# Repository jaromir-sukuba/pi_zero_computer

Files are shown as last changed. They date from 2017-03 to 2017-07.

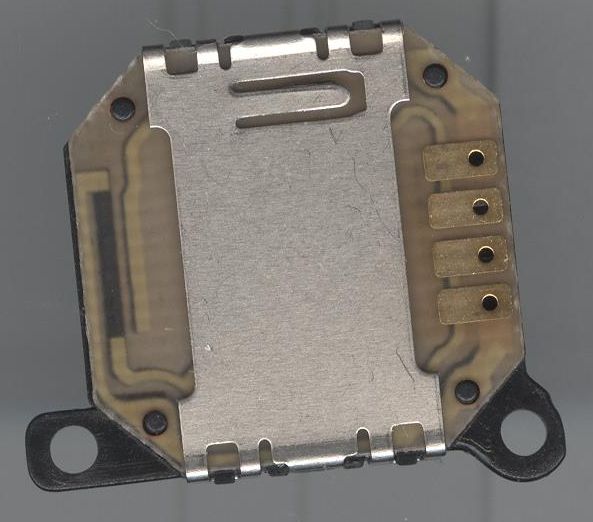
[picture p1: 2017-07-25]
other/joystick_600dpi.jpg

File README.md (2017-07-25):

# Raspberry pi portable computer #

## What it is ##
This is small handheld computer, built around Raspberry Pi Zero, referred as RPi in following articles. Though RPi is often thought to be complete computer, it isn't. You need to add some kind of display, input devices (mouse, keyboard or similar), power supply and perhaps network connection to make it usable by today standards.

My decision was to pack it into small portable form. Raspberry pi laptops have been done to death online, but all of them do miss some features I like to have:

1. All-in-one form factor. I don't want one box for brains, another box for BT keyboard, another for USB hub etc... It is simpler from construction point of view, but the device isn't much usable nor portable.
2. Enclosure sturdy enough so I can put the computer into by backpack with no worries of its disintegration. 
3. At least two USB ports, audio output, battery life at least 5 hours.
4. No major modifications to Raspberry pi. 
5. Easy to replicate by others. I mean - off the shelf components, no complicated wiring (once the PCB is done).

I must admit this computer goes in line with my long term "portable computer fixation", exhibited [before](https://hackaday.io/project/18445-brainfcktor), [and here](https://hackaday.io/project/3511-pavapro-portable-avr-programmer), [also here](https://hackaday.io/project/1757-pp04-camel-computer) or [here too](https://hackaday.io/project/643-minibsd-laptop-computer).



## What it isn't ##
This device isn't superior to thousands or millions manhours of cummulative work put even into the cheapest smartphone you can buy at usual sources. Despite all the work invested into the devices, those are fit to majority of users and (from obvious reasons) often miss details vital for folks like me - full sized USB ports or GPIO pins attached to main processor or 3,5mm audio jack.

## FAQ ##
Q: How is this better than my phone/tablet/smart toaster?

A: If you need to ask this question, then it isn't any better.

## Hardware ##
All hardware is monted on two PCBs, sandwitched together.

The smaller one contains TFT display and a few minor components, vast majority of components is on bottom PCB.



The circuit seems to be complex, but in fact it's only a bit convoluted power supply and user interface. 

RPi acts as heart of this, with USB hub based on FE1.1s, attached to WiFi module, STM32F072 enumerating as USB HID device with two interfaces - one for keyboard (operated by 4x4 matrix keyboard) and one for mouse (operated by analog joystick and three discrete buttons). Audio comes as no surprise to Raspberry pi users, it done by low-pass RC filter and jelly-bean TDA1308 in most common circuit. STM32L011 is connected to RPi by means of serial interface and can turn on/off three power supply voltages (for RPi, for USB, for WiFi) on request of RPi or user. Power is taken from two LiPo cells in series, those are charged by MCP73844 from external 10V source.

Enclosure is designed in FreeCad and printed on hobbyist grade DIY 3D printer

Though self tapered screws would do the job too, I used threaded inserts for machined screws, to allow multiple open-close cycles.


Software
I tried to use as little custom software as possible and rely on existing software drivers. That is behind decision of placing the keyboard behind USB HID wall or using RTL8188EUS module for WiFi. Despite that, device doesn't work as-is with mainstream Raspbian distribution, some customized setup is needed.

* download raspbian, create bootable uSD card and put file ssh.txt into /boot of the uSD card - to allow ssh access to RPi
* connect USB-Ethernet convertor into one USB port of device. 3USD one from Asian sources will do the job
* start device, wait a bit, discover it's IP, login, run raspi-config, setup new password, expand filesystem
* run sudo apt-get update
* run sudo apt-get upgrade
* Add to file /etc/modules-load.d/fbtft.conf
> 	spi-bcm2835
> 	fbtft_device

* Add to file /etc/modprobe.d/fbtft.conf
> 	options fbtft_device custom name=fb_ili9341 gpios=reset:25,dc:24,led:18 speed=16000000 rotate=90 bgr=1

* sudo nano /boot/config.txt
> 	dtoverlay=rpi-display

* sudo reboot
*	sudo nano /boot/cmdline.txt
	
> 	fbcon=map:10 fbcon=font:VGA7x14 logo.nologo

*	sudo nano /usr/share/X11/xorg.conf.d/99-fbdev.conf
> 		Section "Device"
> 		  Identifier "bla"
> 		  Driver "fbdev"
> 		  Option "fbdev" "/dev/fb1"
> 		EndSection
 		
 now you should be able to see display working

* in /boot/config.txt add the following line to enable audio interface:
>     dtoverlay=pwm-2chan,pin=18,func=2,pin2=13,func2=4
>     audio_pwm_mode=2
	
* sudo reboot
* sudo apt-get purge rfkill - to prevent WiFi module from sleeping

## Arduino, just for blog cred ##
Yes, you can upload your arduino sketches in the field


## Miscellany ##
More info is to be found on my [hackady.io page](https://hackaday.io/project/19437-raspberry-pi-zero-handheld-computer)

This project is licensed by MIT license, see LICENSE.md file

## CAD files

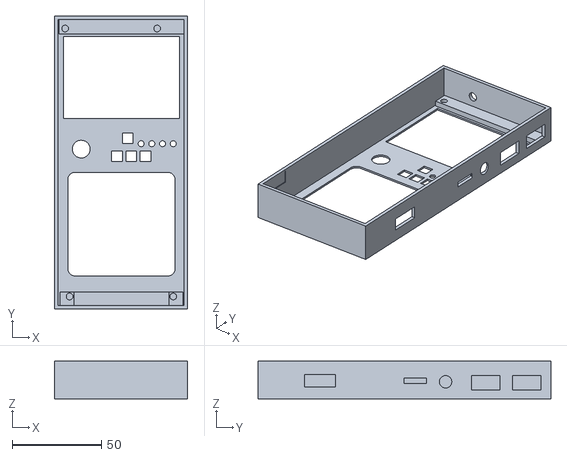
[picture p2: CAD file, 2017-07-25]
mech/1c_main.stl
74.5 x 164.0 x 21.0

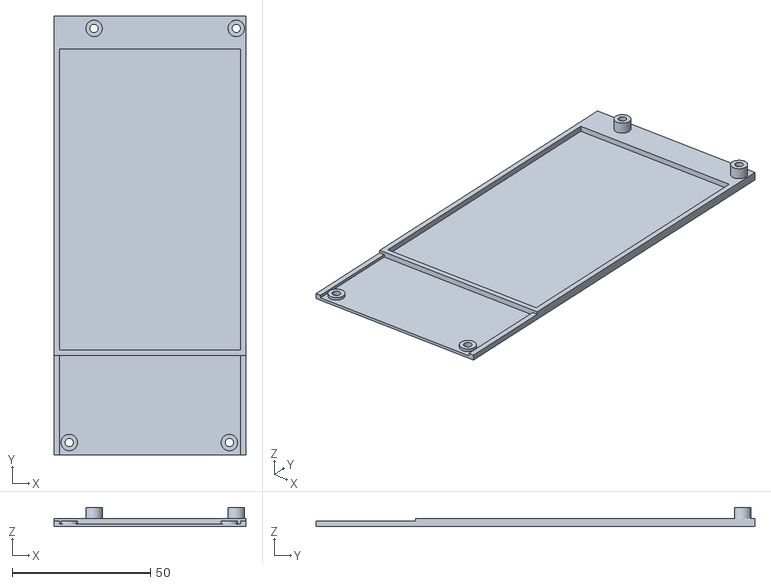
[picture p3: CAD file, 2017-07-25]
mech/1c_btm.stl
69.5 x 159.0 x 7.00

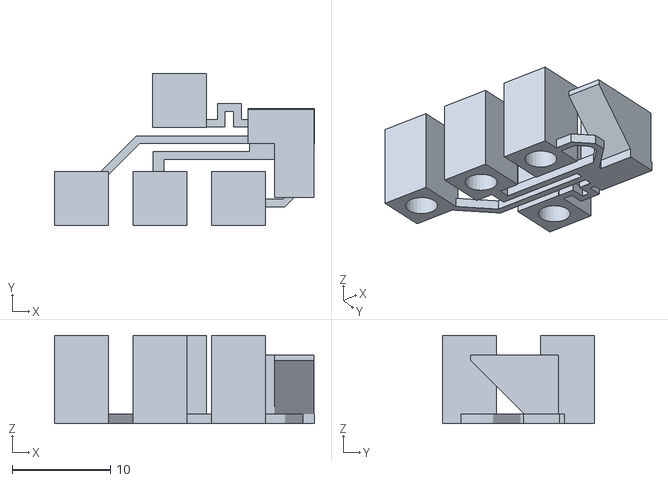
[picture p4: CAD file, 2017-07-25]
mech/1c_btn.stl
26.5 x 15.5 x 9.00

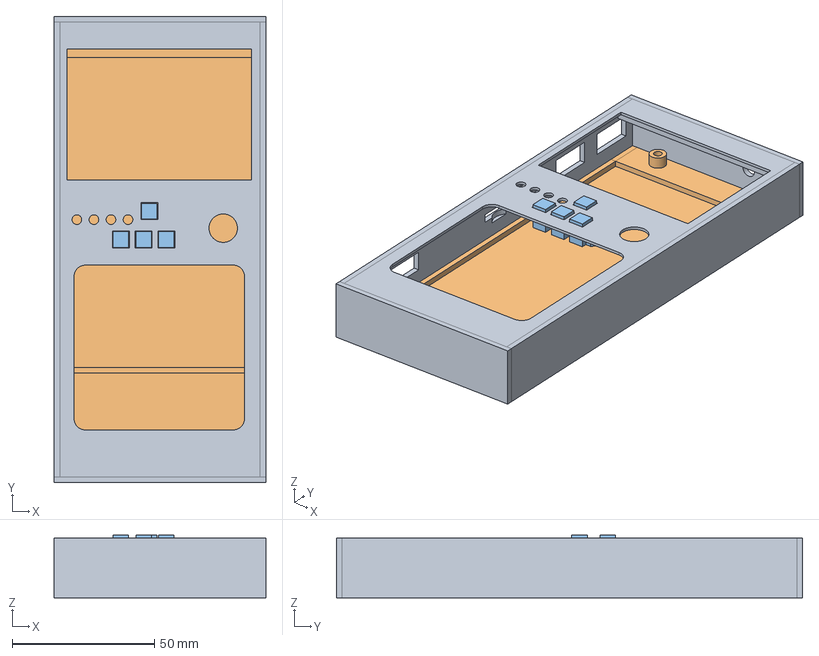
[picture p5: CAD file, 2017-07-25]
mech/m1c.FCStd
74.5 x 164.0 x 22.0 mm
h_plate
buttons

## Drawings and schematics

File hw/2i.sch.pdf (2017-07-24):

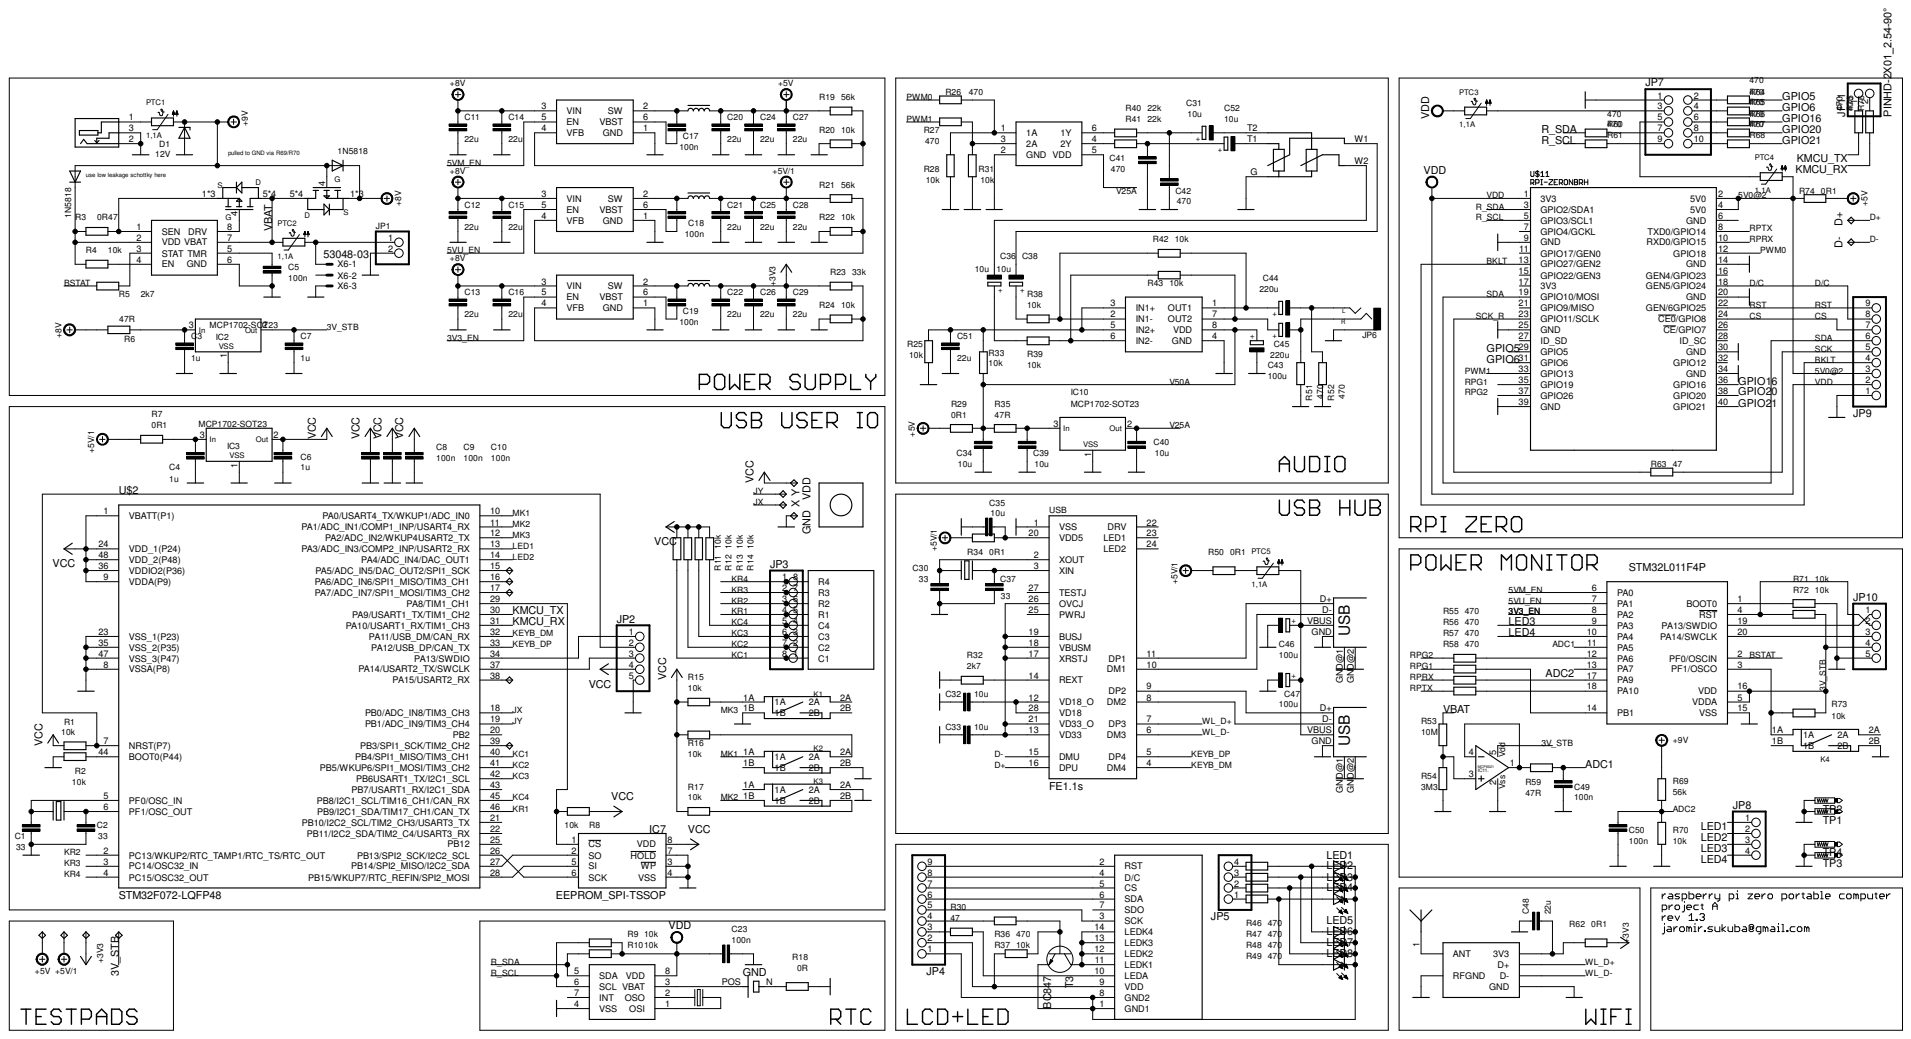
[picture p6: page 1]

+ pulled to GND via R69/R70

use low leakage schottky here

VD18 28 | 7
VD33 13 | 6 DP3 | VBUS

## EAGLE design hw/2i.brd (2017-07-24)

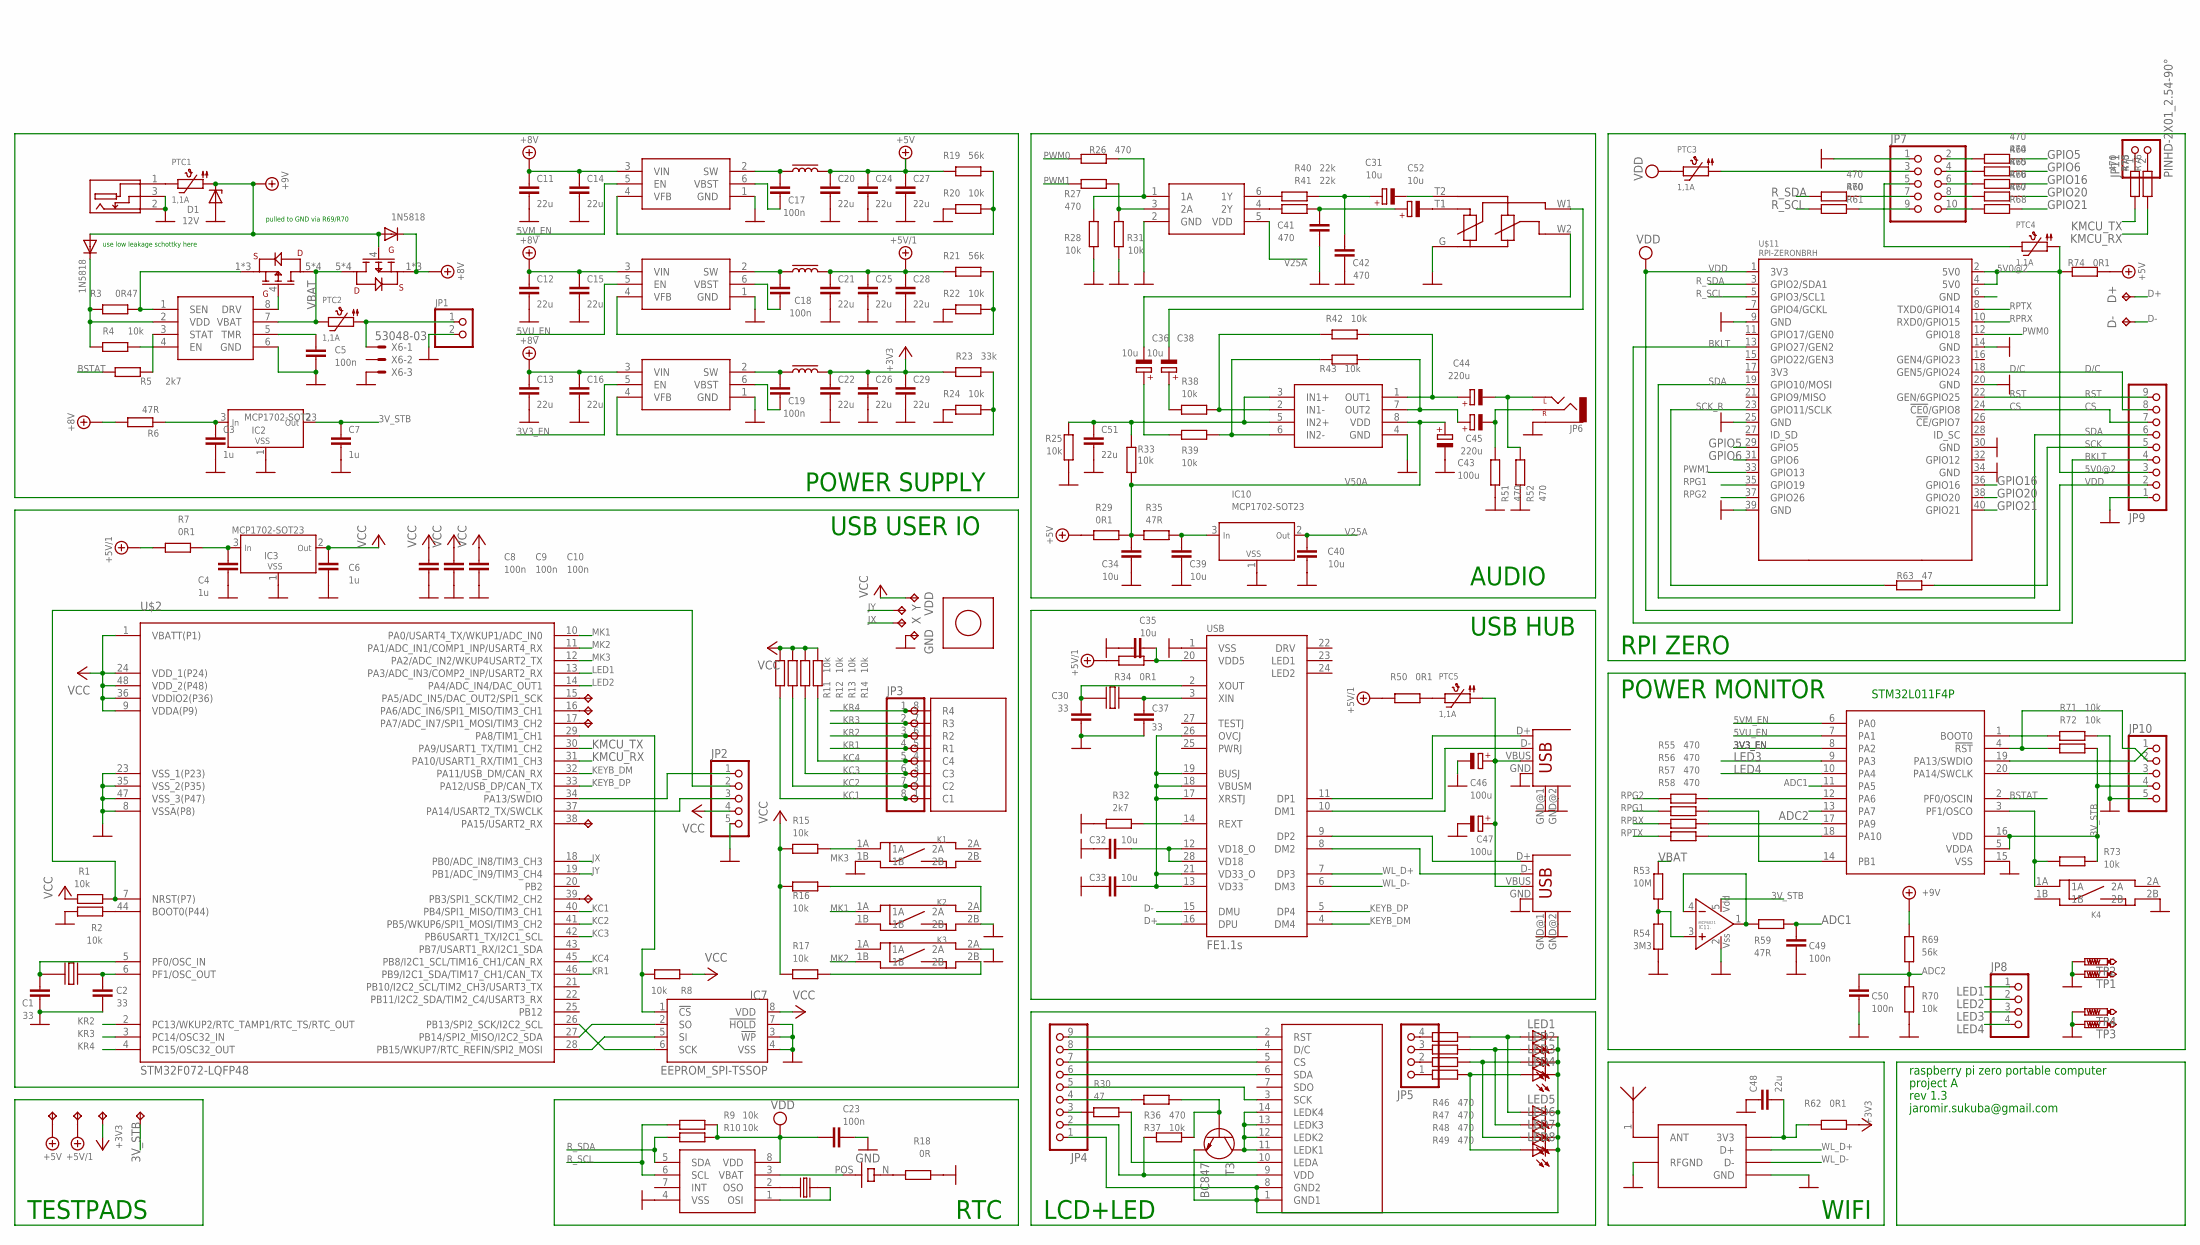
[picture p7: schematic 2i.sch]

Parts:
ANT1: ANT_RAINSUN_24GHZ; ANT_RAINSUN-24G
C1, C2, C30, C37: 33; R0805
C3, C4, C6, C7: 1u; R0805
C5, C8, C9, C10, C17, C18, C19, C23, C49, C50: 100n; R0805
C11, C12, C13, C14, C15, C16, C20, C21, C22, C24, C25, C26, C27, C28, C29, C48, C51: 22u; R0805
C31, C36, C38, C52: 10u; PANASONIC_A
C32, C33, C34, C35, C39, C40: 10u; R0805
C41, C42: 470; R0805
C43, C46, C47: 100u; PANASONIC_D
C44, C45: 220u; PANASONIC_D
D1: 12V; SMB
D2, D3: 1N5818; SMB
D+: TPTP14R; TP14R
D-: TPTP14R; TP14R
GND: TPTP14R; TP14R
IC1: MCP73844; MSOP8
IC2, IC3, IC10: MCP1702-SOT23; SOT23
IC4, IC5, IC6: TPS562200; SOT23-6
IC7: EEPROM_SPI-TSSOP; TSSOP8W
IC8: PCF8523; SO-08
IC9: 74LVC2G34; SOT23-6
IC11: MCP6021; SOT23-5L
JP1: PINHD-1X02_2.54-90°; 1X02/90
JP2, JP10: PINHD-1X05_2.54-90°; 1X05/90
JP3: PINHD-1X08_2.54; 1X08
JP4, JP9: PINHD-1X09_2.00; 1X09M
JP5, JP8: PINHD-1X04_2.00; 1X04M
JP6: AUDIO-JACKPTH; AUDIO-JACK
JP7: PINHD-2X05_2.54-90°; 2X05/90
JP11: PINHD-2X01_2.54-90°; 2X01/90
K1, K2, K3, K4: SWITCH_BD_B; SW_SMD2
LED1, LED2, LED3, LED4: LED3MM
LED5, LED6, LED7, LED8: LEDCHIPLED_0805; CHIPLED_0805
MOD1: MOD_USB_RTL8188
PTC1, PTC2, PTC3, PTC4, PTC5: 1,1A; PTC1812
Q1: CRYSTAL87X38; CRYST_32K_87X38MM
R1, R2, R4, R8, R9, R10, R11, R12, R13, R14, R15, R16, R17, R20, R22, R24, R25, R28, R31, R33, R37, R38, R39, R42, R43, R70, R71, R72, R73: 10k; R0805
R3: 0R47; R1206
R5, R32: 2k7; R0805
R6, R35, R59: 47R; R0805
R7, R29, R34, R50, R62, R74: 0R1; R1206
R18: 0R; R0805
R19, R21, R69: 56k; R0805
R23: 33k; R0805
R26, R27, R36, R46, R47, R48, R49, R51, R52, R55, R56, R57, R58, R60, R61, R64, R65, R66, R67, R68, R75, R76: 470; R0805
R30, R63: 47; R0805
R40, R41: 22k; R0805
R53: 10M; R0805
R54: 3M3; R0805
T1, T2: PFET_SO8; SO-08
T3: BC847; SOT23
TFT1: DISP_ILI_28
TP1, TP2, TP3, TP4: PTR1PAD1-13; P1-13
U$1: CONN_DC_13; CON_DC13
U$2: STM32F072-LQFP48; LQFP48
U$3, U$4, U$5: 2u2; BOURNS_SRP7030
U$6: BATTH1220; BATT_HOLDER_DS1092-12
U$7: KB1604
U$8: JOY_PS
U$9: TDA1308; SO-08
U$10: POT_DUAL_14X2; POT_14X2DUAL
U$11: RPI-ZERONBRH; RPI_ZERO_NBRH
U$12: STM32F030_20; TSSOP20
USB: FE1.1S; FE1.1S_SSOP-28
USB1, USB2: USB-A-S
VDD: TPTP14R; TP14R
X, X1, X3, X4, X5, X7, X8, X9, X12, X13: TPTP14R; TP14R
X2, X14: CRYST_TC26SMXAS; CR_12SMXA_S
X6: 53048-03
Y: TPTP14R; TP14R

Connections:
3V3_EN: IC6.5 (EN), U$12.8 (PA2)
3V_STB: C7.1, IC2.2 (OUT), IC11.5 (VDD), JP10.4, R72.2, R73.2, U$12.5 (VDDA), U$12.16 (VDD), X5.TP
5V0@2: JP9.3, PTC4.P$1 (1), R74.2, U$11.2 (5V0), U$11.4 (5V0)
5VM_EN: IC4.5 (EN), U$12.6 (PA0)
5VU_EN: IC5.5 (EN), U$12.7 (PA1)
+3V3: C22.1, C26.1, C29.1, R23.1, R62.1, U$5.P$2, X4.TP
+5V: C20.1, C24.1, C27.1, R19.1, R29.2, R74.1, U$3.P$2, X1.TP
+5V/1: C21.1, C25.1, C28.1, R7.1, R21.1, R34.2, R50.2, U$4.P$2, X3.TP
+8V: C11.1, C12.1, C13.1, C14.1, C15.1, C16.1, D3.C, IC4.3 (VIN), IC5.3 (VIN), IC6.3 (VIN), R6.2, T2.1 (S), T2.2 (S), T2.3 (S)
+9V: D1.C, D2.A, D3.A, PTC1.P$1 (1), R69.2, T2.4 (G)
ADC1: C49.2, R59.1, U$12.11 (PA5)
ADC2: C50.2, R69.1, R70.2, U$12.13 (PA7)
BKLT: JP9.4, U$11.13 (GPIO27/GEN2)
BSTAT: R5.2, U$12.2 (PF0/OSCIN)
CS: JP9.7, U$11.24 (!CE0!/GPIO8)
D+: D+.TP, USB.16 (DPU)
D-: D-.TP, USB.15 (DMU)
D/C: JP9.8, U$11.18 (GEN5/GPIO24)
GND: C1.1, C2.1, C3.2, C4.2, C5.2, C6.2, C7.2, C8.2, C9.2, C10.2, C11.2, C12.2, C13.2, C14.2, C15.2, C16.2, C20.2, C21.2, C22.2, C23.2, C24.2, C25.2, C26.2, C27.2, C28.2, C29.2, C30.1, C32.1, C33.1, C34.1, C35.1, C37.1, C39.1, C40.1, C41.1, C42.1, C43.-, C46.-, C47.-, C48.1, C49.1, C50.1, C51.2, D1.A, GND.TP, IC1.6 (GND), IC2.1 (VSS), IC3.1 (VSS), IC4.1 (GND), IC5.1 (GND), IC6.1 (GND), IC7.3 (!WP), IC7.4 (VSS), IC7.7 (!HOLD), IC8.4 (VSS), IC9.2 (GND), IC10.1 (VSS), IC11.2 (VSS), JP1.2, JP2.5, JP6.SLEEVE, JP7.1, JP9.1, JP10.5, K1.1B, K2.2B, K3.2A, K4.2B, MOD1.GND, MOD1.RFGND, R2.2, R18.1, R20.1, R22.1, R24.1, R25.1, R28.1, R31.1, R32.1, R51.2, R52.2, R54.1, R70.1, R71.2, TP1.TP, TP2.TP, TP3.TP, TP4.TP, U$1.2 (N), U$1.3 (SW), U$2.8 (VSSA(P8)), U$2.23 (VSS_1(P23)), U$2.35 (VSS_2(P35)), U$2.47 (VSS_3(P47)), U$9.4 (GND), U$10.G, U$11.9 (GND), U$11.14 (GND), U$11.20 (GND), U$11.25 (GND), U$11.30 (GND), U$11.34 (GND), U$11.39 (GND), U$12.15 (VSS), USB.1 (VSS), USB1.GND, USB1.GND@1 (GND), USB1.GND@2 (GND), USB2.GND, USB2.GND@1 (GND), USB2.GND@2 (GND), X6.3
GND@8: U$11.6 (GND)
GPIO5: R64.2, U$11.29 (GPIO5)
GPIO6: R65.2, U$11.31 (GPIO6)
GPIO16: R66.2, U$11.36 (GPIO16)
GPIO20: R67.2, U$11.38 (GPIO20)
GPIO21: R68.2, U$11.40 (GPIO21)
JX: U$2.18 (PB0/ADC_IN8/TIM3_CH3), X.TP
JY: U$2.19 (PB1/ADC_IN9/TIM3_CH4), Y.TP
KC1: JP3.8, R11.1, U$2.40 (PB4/SPI1_MISO/TIM3_CH1), U$7.1 (C1)
KC2: JP3.7, R12.1, U$2.41 (PB5/WKUP6/SPI1_MOSI/TIM3_CH2), U$7.2 (C2)
KC3: JP3.6, R13.1, U$2.42 (PB6USART1_TX/I2C1_SCL), U$7.3 (C3)
KC4: JP3.5, R14.1, U$2.45 (PB8/I2C1_SCL/TIM16_CH1/CAN_RX), U$7.4 (C4)
KEYB_DM: U$2.32 (PA11/USB_DM/CAN_RX), USB.4 (DM4)
KEYB_DP: U$2.33 (PA12/USB_DP/CAN_TX), USB.5 (DP4)
KMCU_RX: R76.1, U$2.31 (PA10/USART1_RX/TIM1_CH3)
KMCU_TX: R75.1, U$2.30 (PA9/USART1_TX/TIM1_CH2)
KR1: JP3.4, U$2.46 (PB9/I2C1_SDA/TIM17_CH1/CAN_TX), U$7.5 (R1)
KR2: JP3.3, U$2.2 (PC13/WKUP2/RTC_TAMP1/RTC_TS/RTC_OUT), U$7.6 (R2)
KR3: JP3.2, U$2.3 (PC14/OSC32_IN), U$7.7 (R3)
KR4: JP3.1, U$2.4 (PC15/OSC32_OUT), U$7.8 (R4)
LED1: JP8.1, U$2.13 (PA3/ADC_IN3/COMP2_INP/USART2_RX)
LED2: JP8.2, U$2.14 (PA4/ADC_IN4/DAC_OUT1)
LED3: JP8.3, U$12.9 (PA3)
LED4: JP8.4, U$12.10 (PA4)
MK1: K2.1A, U$2.10 (PA0/USART4_TX/WKUP1/ADC_IN0)
MK2: K3.1B, U$2.11 (PA1/ADC_IN1/COMP1_INP/USART4_RX)
MK3: K1.1A, R15.2, U$2.12 (PA2/ADC_IN2/WKUP4USART2_TX)
unnamed: C35.2, R34.1, USB.20 (VDD5)
unnamed: C17.2, IC4.2 (SW), U$3.P$1
unnamed: JP4.3, R30.2
unnamed: IC7.6 (SCK), U$2.26 (PB13/SPI2_SCK/I2C2_SCL)
unnamed: R36.2, R37.1, T3.1 (B)
unnamed: JP4.4, R36.1
unnamed: IC1.1 (SEN), R3.2, T1.1 (S), T1.2 (S), T1.3 (S)
unnamed: USB.9 (DP2), USB2.D+
unnamed: USB.8 (DM2), USB2.D-
unnamed: USB.10 (DM1), USB1.D-
unnamed: IC1.8 (DRV), T1.4 (G)
unnamed: IC1.4 (EN), R4.2
unnamed: USB.11 (DP1), USB1.D+
unnamed: C33.2, USB.13 (VD33), USB.17 (XRSTJ), USB.18 (VBUSM), USB.19 (BUSJ), USB.21 (VD33_O), USB.26 (OVCJ)
unnamed: IC11.1 (VYSTUP), IC11.4 (IN-), R59.2
unnamed: C32.2, USB.12 (VD18_O), USB.28 (VD18)
unnamed: C5.1, IC1.5 (TMR)
unnamed: C17.1, IC4.6 (VBST)
unnamed: R32.2, USB.14 (REXT)
unnamed: IC4.4 (VFB), R19.2, R20.2
unnamed: C30.2, USB.2 (XOUT), X14.P$1
unnamed: C18.2, IC5.2 (SW), U$4.P$1
unnamed: C18.1, IC5.6 (VBST)
unnamed: C37.2, USB.3 (XIN), X14.P$2
unnamed: C46.+, C47.+, PTC5.P$1 (1), USB1.VBUS, USB2.VBUS
unnamed: IC7.2 (SO), U$2.27 (PB14/SPI2_MISO/I2C2_SDA)
unnamed: IC9.6 (1Y), R40.2
unnamed: IC9.4 (2Y), R41.2
unnamed: C31.+, C42.2, R40.1
unnamed: C41.2, C52.+, R41.1
unnamed: C44.-, JP6.TIP (LEFT), R52.1
unnamed: C45.-, JP6.RING (RIGHT), R51.1
unnamed: C44.+, R42.2, U$9.1 (OUT1)
unnamed: C45.+, R43.2, U$9.7 (OUT2)
unnamed: C51.1, R25.2, R33.1, U$9.3 (IN1+), U$9.5 (IN2+)
unnamed: R38.2, R42.1, U$9.2 (IN1-)
unnamed: R39.2, R43.1, U$9.6 (IN2-)
unnamed: C38.+, R38.1
unnamed: C36.+, R39.1
unnamed: C36.-, U$10.W2
unnamed: C38.-, U$10.W1
unnamed: ANT1.1, MOD1.ANT
unnamed: JP11.1, R75.2
unnamed: IC5.4 (VFB), R21.2, R22.2
unnamed: C19.2, IC6.2 (SW), U$5.P$1
unnamed: C19.1, IC6.6 (VBST)
unnamed: JP2.1, U$2.34 (PA13/SWDIO)
unnamed: IC6.4 (VFB), R23.2, R24.2
unnamed: C4.1, IC3.3 (IN), R7.2
unnamed: JP2.3, U$2.37 (PA14/USART2_TX/SWCLK)
unnamed: D2.C, IC1.2 (VDD), R3.1, R4.1
unnamed: PTC1.P$2 (2), U$1.1
unnamed: IC9.1 (1A), R26.1, R28.2
unnamed: IC9.3 (2A), R27.1, R31.2
unnamed: C1.2, U$2.5 (PF0/OSC_IN), X2.P$1
unnamed: JP11.2, R76.2
unnamed: IC7.5 (SI), U$2.28 (PB15/WKUP7/RTC_REFIN/SPI2_MOSI)
unnamed: IC7.1 (!CS), R8.2, U$2.29 (PA8/TIM1_CH1)
unnamed: R56.2, U$12.14 (PB1)
unnamed: U$2.15 (PA5/ADC_IN5/DAC_OUT2/SPI1_SCK), X7.TP
unnamed: R2.1, U$2.44 (BOOT0(P44))
unnamed: JP5.4, R46.2
unnamed: JP5.3, R47.2
unnamed: JP5.2, R48.2
unnamed: JP5.1, R49.2
unnamed: JP2.2, R1.1, U$2.7 (NRST(P7))
unnamed: R57.2, U$12.17 (PA9)
unnamed: R58.2, U$12.18 (PA10)
unnamed: PTC5.P$2 (2), R50.1
unnamed: R55.2, U$12.12 (PA6)
unnamed: U$2.16 (PA6/ADC_IN6/SPI1_MISO/TIM3_CH1), X8.TP
unnamed: U$2.17 (PA7/ADC_IN7/SPI1_MOSI/TIM3_CH2), X9.TP
unnamed: U$2.38 (PA15/USART2_RX), X12.TP
unnamed: U$2.39 (PB3/SPI1_SCK/TIM2_CH2), X13.TP
unnamed: JP10.1, U$12.19 (PA13/SWDIO)
unnamed: JP10.3, U$12.20 (PA14/SWCLK)
unnamed: JP10.2, R72.1, U$12.4 (!RST)
unnamed: JP1.1, PTC2.P$1 (1), X6.1
unnamed: C52.-, U$10.T1
unnamed: K4.1A, R73.1, U$12.3 (PF1/OSCO)
unnamed: C2.2, U$2.6 (PF1/OSC_OUT), X2.P$2
unnamed: IC8.3 (VBAT), U$6.POS
unnamed: R18.2, U$6.N (M)
unnamed: LED1.A, LED5.A, R46.1
unnamed: LED2.A, LED6.A, R47.1
unnamed: K3.2B, R17.2
unnamed: IC8.2 (OSO), Q1.4 (2)
unnamed: IC8.1 (OSI), Q1.1
unnamed: K2.2A, R16.2
unnamed: LED3.A, LED7.A, R48.1
unnamed: LED4.A, LED8.A, R49.1
unnamed: JP4.5, TFT1.3 (SCK)
unnamed: JP4.1, LED1.K (C), LED2.K (C), LED3.K (C), LED4.K (C), LED5.C, LED6.C, LED7.C, LED8.C, T3.2 (E), TFT1.1 (GND1), TFT1.8 (GND2)
unnamed: T3.3 (C), TFT1.11 (LEDK1), TFT1.12 (LEDK2), TFT1.13 (LEDK3), TFT1.14 (LEDK4)
unnamed: JP7.5, PTC4.P$2 (2)
unnamed: IC1.3 (STAT), R5.1
unnamed: JP7.3, PTC3.P$1 (1)
unnamed: C48.2, MOD1.3V3, R62.2
unnamed: IC11.3 (NEIN+), R53.1, R54.2
unnamed: C3.1, IC2.3 (IN), R6.1
unnamed: R71.1, U$12.1 (BOOT0)
unnamed: C31.-, U$10.T2
unnamed: R30.1, TFT1.10 (LEDA)
unnamed: JP4.2, R37.2, TFT1.9 (VDD)
unnamed: C39.2, IC10.3 (IN), R35.2
unnamed: JP4.6, TFT1.6 (SDA)
unnamed: JP4.7, TFT1.5 (CS)
unnamed: JP4.8, TFT1.4 (D/C)
unnamed: JP4.9, TFT1.2 (RST)
unnamed: JP7.10, R68.1
unnamed: JP7.8, R67.1
unnamed: JP7.6, R66.1
unnamed: JP7.4, R65.1
unnamed: JP7.2, R64.1
unnamed: JP7.7, R60.2
unnamed: JP7.9, R61.2
PWM0: R27.2, U$11.12 (GPIO18)
PWM1: R26.2, U$11.33 (GPIO13)
RPG1: R56.1, U$11.35 (GPIO19)
RPG2: R55.1, U$11.37 (GPIO26)
RPRX: R57.1, U$11.10 (RXD0/GPIO15)
RPTX: R58.1, U$11.8 (TXD0/GPIO14)
RST: JP9.9, U$11.22 (GEN/6GPIO25)
R_SCL: IC8.6 (SCL), R9.1, R61.1, U$11.5 (GPIO3/SCL1)
R_SDA: IC8.5 (SDA), R10.1, R60.1, U$11.3 (GPIO2/SDA1)
SCK: JP9.5, R63.1
SCK_R: R63.2, U$11.23 (GPIO11/SCLK)
SDA: JP9.6, U$11.19 (GPIO10/MOSI)
V25A: C40.2, IC9.5 (VDD), IC10.2 (OUT)
V50A: C34.2, C43.+, R29.1, R33.2, R35.1, U$9.8 (VDD)
VBAT: IC1.7 (VBAT), PTC2.P$2 (2), R53.2, T1.5 (D), T1.6 (D), T1.7 (D), T1.8 (D), T2.5 (D), T2.6 (D), T2.7 (D), T2.8 (D)
VCC: C6.1, C8.1, C9.1, C10.1, IC3.2 (OUT), IC7.8 (VDD), JP2.4, R1.2, R8.1, R11.2, R12.2, R13.2, R14.2, R15.1, R16.1, R17.1, U$2.1 (VBATT(P1)), U$2.9 (VDDA(P9)), U$2.24 (VDD_1(P24)), U$2.36 (VDDIO2(P36)), U$2.48 (VDD_2(P48)), VDD.TP
VDD: C23.1, IC8.8 (VDD), JP9.2, PTC3.P$2 (2), R9.2, R10.2, U$11.1 (3V3)
WL_D+: MOD1.D+, USB.7 (DP3)
WL_D-: MOD1.D-, USB.6 (DM3)

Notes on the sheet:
POWER SUPPLY
USB USER IO
RPI ZERO
POWER MONITOR
WIFI
LCD+LED
USB HUB
AUDIO
raspberry pi zero portable computer
project A
rev 1.3
RTC
jaromir.sukuba@gmail.com
pulled to GND via R69/R70
use low leakage schottky here
TESTPADS
STM32L011F4P

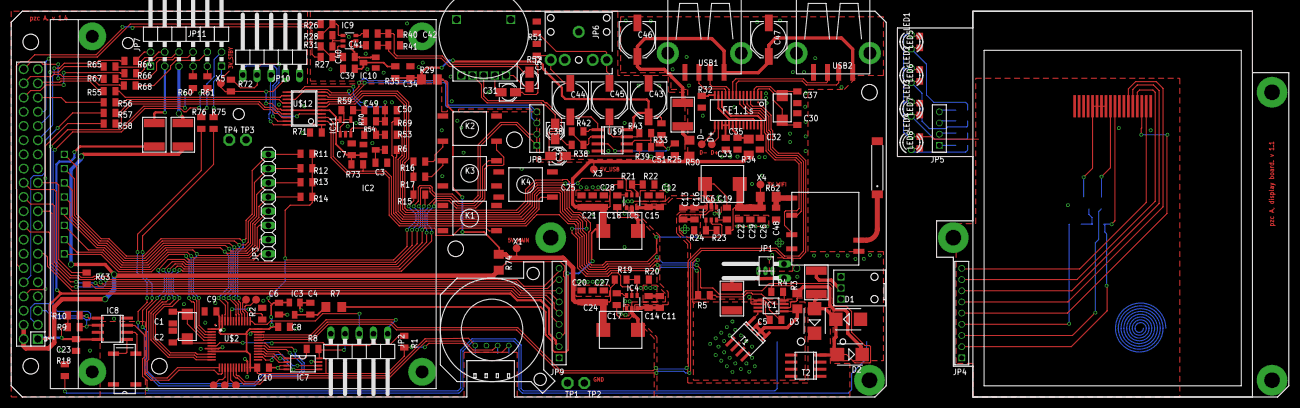
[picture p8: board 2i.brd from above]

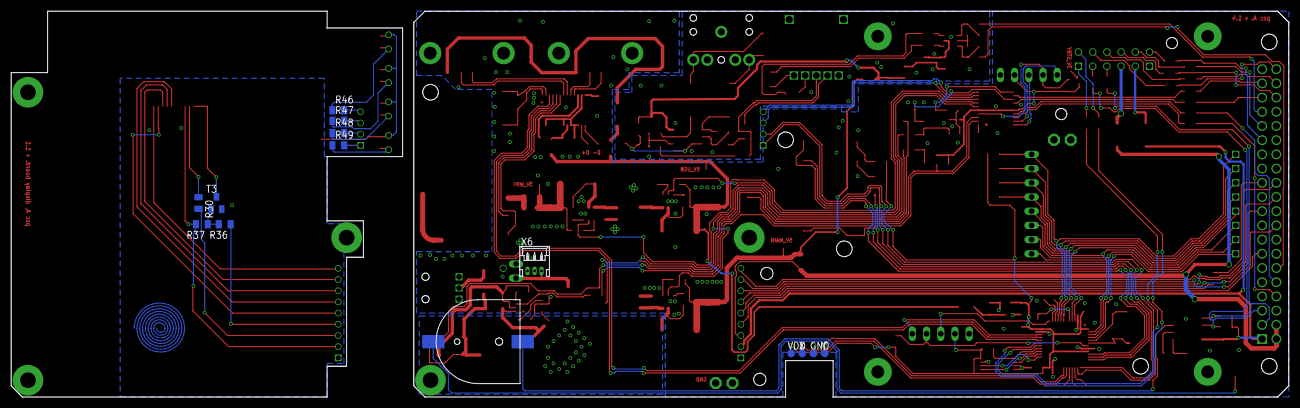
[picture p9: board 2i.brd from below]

Board: 2 copper layers, 228.5 x 69.0 mm, 212 parts (14 on the bottom side), 180 nets.

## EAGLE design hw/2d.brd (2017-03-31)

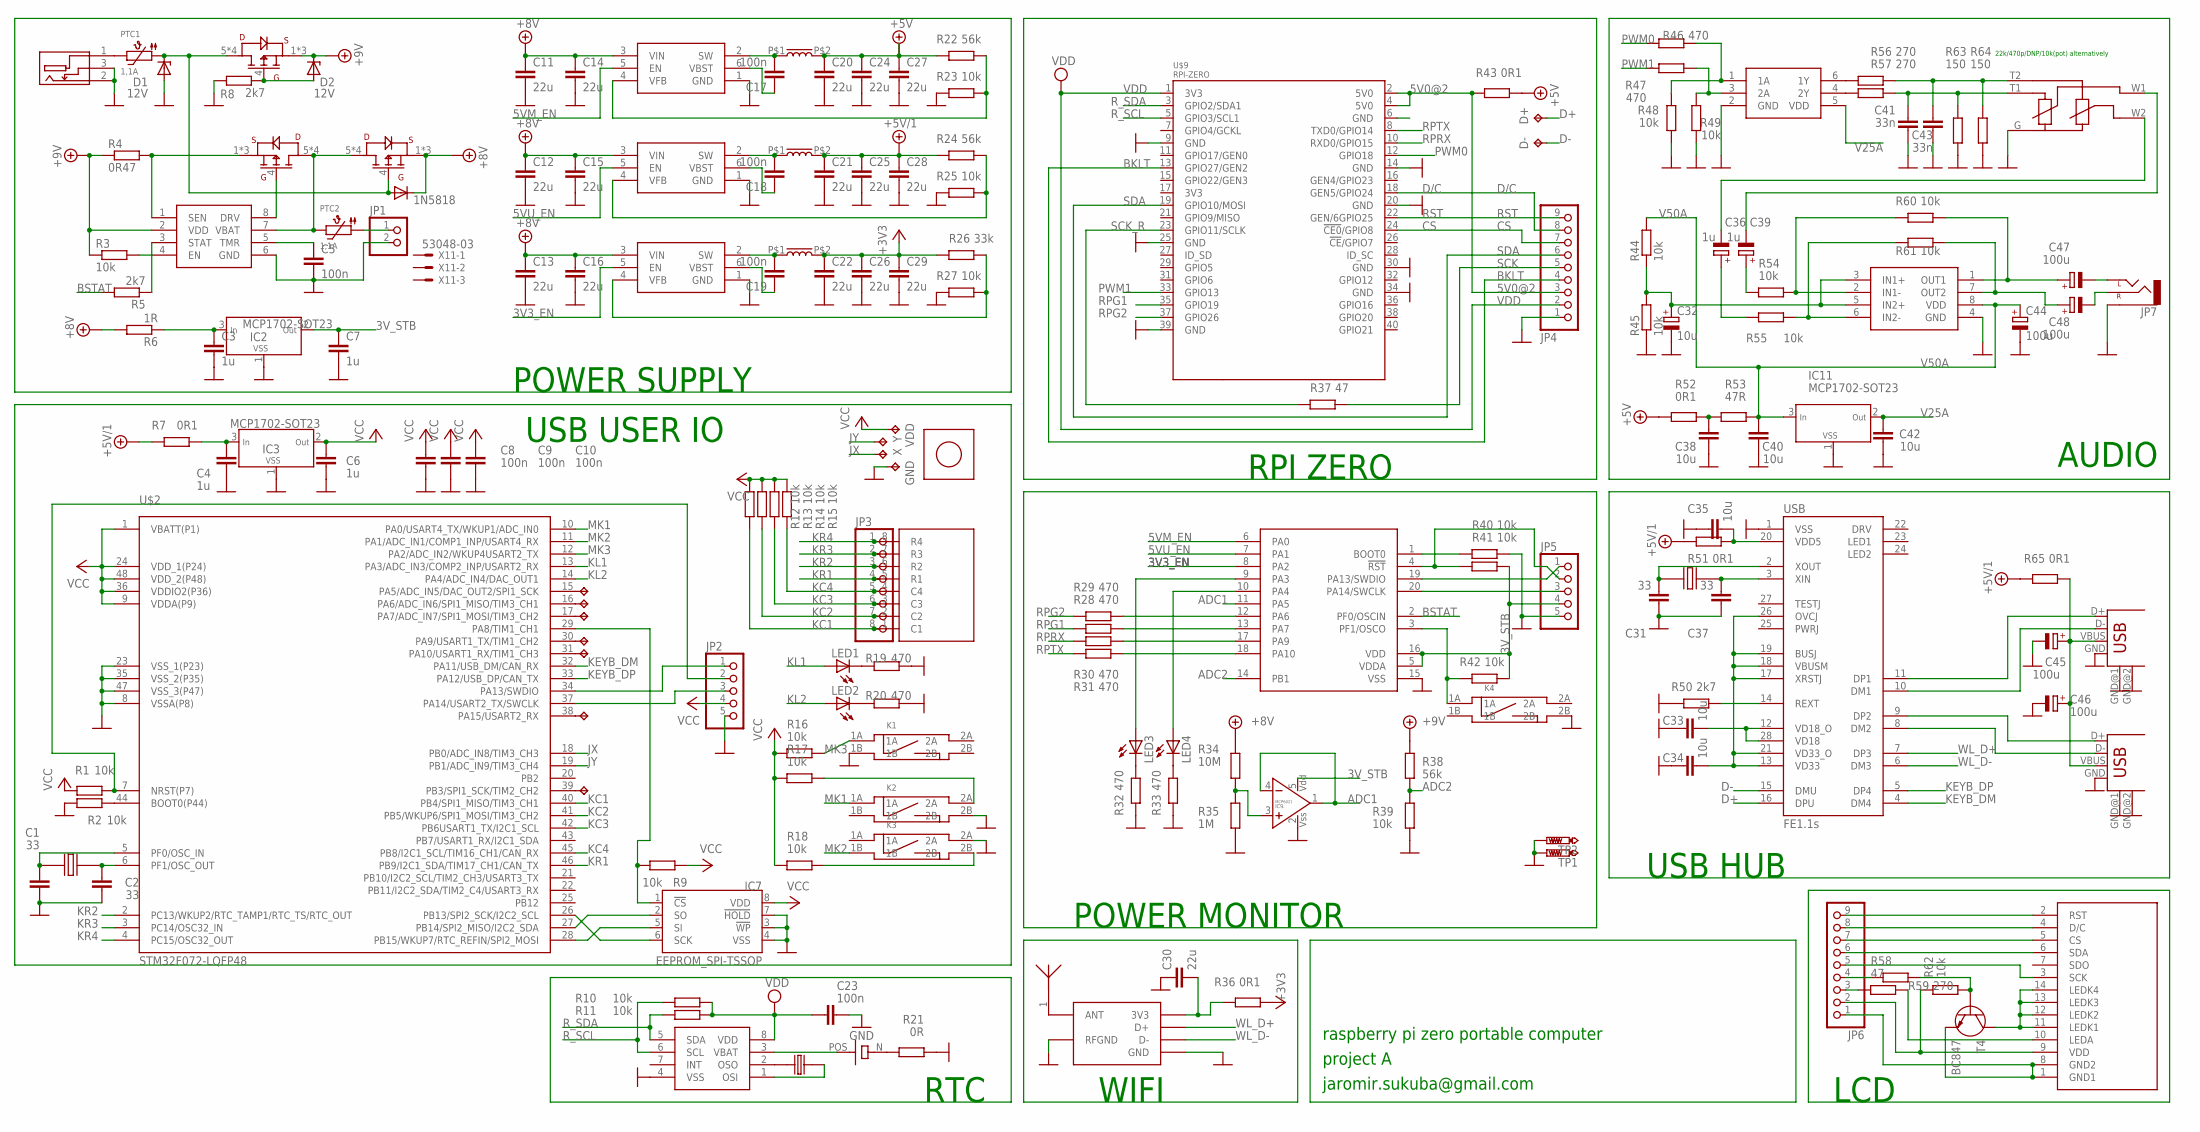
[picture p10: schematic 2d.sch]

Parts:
ANT1: ANT_RAINSUN_24GHZ; ANT_RAINSUN-24G
C1, C2, C31, C37: 33; R0805
C3, C4, C6, C7: 1u; R0805
C5, C8, C9, C10, C17, C18, C19, C23: 100n; R0805
C11, C12, C13, C14, C15, C16, C20, C21, C22, C24, C25, C26, C27, C28, C29, C30: 22u; R0805
C32: 10u; PANASONIC_B
C33, C34, C35, C38, C40, C42: 10u; R0805
C36, C39: 1u; PANASONIC_A
C41, C43: 33n; R0805
C44, C45, C46, C47, C48: 100u; PANASONIC_D
D1: 12V; SMB
D2: 12V; SOD80C
D3: 1N5818; SMB
D+: TPTP14R; TP14R
D-: TPTP14R; TP14R
GND: TPTP14R; TP14R
IC1: MCP73844; MSOP8
IC2, IC3, IC11: MCP1702-SOT23; SOT23
IC4, IC5, IC6: TPS562200; SOT23-6
IC7: EEPROM_SPI-TSSOP; TSSOP8W
IC8: PCF8523; SO-08
IC9: MCP6021; SOT23-5L
IC10: 74LVC2G34; SOT23-6
JP1: PINHD-1X02_2.54-90°; 1X02/90
JP2, JP5: PINHD-1X05_2.54-90°; 1X05/90
JP3: PINHD-1X08_2.54; 1X08
JP4, JP6: PINHD-1X09_2.00; 1X09M
JP7: AUDIO-JACKPTH; AUDIO-JACK
K1, K2, K3, K4: SWITCH_BD_B; SW_SMD2
LED1, LED2, LED3, LED4: LED3MM
MOD1: MOD_USB_RTL8188
PTC1, PTC2: 1,1A; PTC1812
Q1: CRYSTAL87X38; CRYST_32K_87X38MM
R1, R2, R3, R9, R10, R11, R12, R13, R14, R15, R16, R17, R18, R23, R25, R27, R39, R40, R41, R42, R44, R45, R48, R49, R54, R55, R60, R61, R62: 10k; R0805
R4: 0R47; R1206
R5, R8, R50: 2k7; R0805
R6: 1R; R0805
R7, R36, R43, R51, R52, R65: 0R1; R1206
R19, R20, R28, R29, R30, R31, R32, R33, R46, R47: 470; R0805
R21: 0R; R0805
R22, R24, R38: 56k; R0805
R26: 33k; R0805
R34: 10M; R0805
R35: 1M; R0805
R37, R58: 47; R0805
R53: 47R; R0805
R56, R57, R59: 270; R0805
R63, R64: 150; R0805
T1, T2, T3: PFET_SO8; SO-08
T4: BC847; SOT23
TFT1: DISP_ILI_28
TP1, TP2: PTR1PAD1-13; P1-13
U$1: CONN_DC_13; CON_DC13
U$2: STM32F072-LQFP48; LQFP48
U$3, U$4, U$5: 2u2; BOURNS_SRP7030
U$6: BATTH1220; BATT_HOLDER_DS1092-12
U$7: KB1604
U$8: JOY_PS
U$9: RPI-ZERO; RASPBERRYPI_BASTELSTUBE_V13_RASPI_BOARD_B+_FULL
U$10: STM32F030_20; TSSOP20
U$11: TDA1308; SO-08
U$12: POT_DUAL_14X2; POT_14X2DUAL
USB: FE1.1S; FE1.1S_SSOP-28
USB1, USB2: USB-A-S
VDD: TPTP14R; TP14R
X, X2, X3, X4, X5, X6, X7, X8: TPTP14R; TP14R
X1, X9: CRYST_TC26SMXAS; CR_12SMXA_S
X11: 53048-03
Y: TPTP14R; TP14R

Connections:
3V3_EN: IC6.5 (EN), U$10.8 (PA2)
3V_STB: C7.1, IC2.2 (OUT), IC9.5 (VDD), JP5.4, R41.2, R42.2, U$10.5 (VDDA), U$10.16 (VDD)
5V0@2: JP4.3, R43.2, U$9.2 (5V0), U$9.4 (5V0)
5VM_EN: IC4.5 (EN), U$10.6 (PA0)
5VU_EN: IC5.5 (EN), U$10.7 (PA1)
+3V3: C22.1, C26.1, C29.1, R26.1, R36.1, U$5.P$2
+5V: C20.1, C24.1, C27.1, R22.1, R43.1, R52.2, U$3.P$2
+5V/1: C21.1, C25.1, C28.1, R7.1, R24.1, R51.2, R65.2, U$4.P$2
+8V: C11.1, C12.1, C13.1, C14.1, C15.1, C16.1, D3.C, IC4.3 (VIN), IC5.3 (VIN), IC6.3 (VIN), R6.2, R34.2, T3.1 (S), T3.2 (S), T3.3 (S)
+12V: D2.C, IC1.2 (VDD), R3.1, R4.1, R38.2, T1.1 (S), T1.2 (S), T1.3 (S)
ADC1: IC9.1 (VYSTUP), IC9.4 (IN-), U$10.11 (PA5)
ADC2: R38.1, R39.2, U$10.14 (PB1)
BKLT: JP4.4, U$9.13 (GPIO27/GEN2)
BSTAT: R5.2, U$10.2 (PF0/OSCIN)
CS: JP4.7, U$9.24 (!CE0!/GPIO8)
D+: D+.TP, USB.16 (DPU)
D-: D-.TP, USB.15 (DMU)
D/C: JP4.8, U$9.18 (GEN5/GPIO24)
GND: C1.1, C2.1, C3.2, C4.2, C5.2, C6.2, C7.2, C8.2, C9.2, C10.2, C11.2, C12.2, C13.2, C14.2, C15.2, C16.2, C20.2, C21.2, C22.2, C23.2, C24.2, C25.2, C26.2, C27.2, C28.2, C29.2, C30.1, C31.1, C32.-, C33.1, C34.1, C35.1, C37.1, C38.1, C40.1, C41.1, C42.1, C43.1, C44.-, C45.-, C46.-, D1.A, GND.TP, IC1.6 (GND), IC2.1 (VSS), IC3.1 (VSS), IC4.1 (GND), IC5.1 (GND), IC6.1 (GND), IC7.3 (!WP), IC7.4 (VSS), IC7.7 (!HOLD), IC8.4 (VSS), IC9.2 (VSS), IC10.2 (GND), IC11.1 (VSS), JP1.2, JP2.5, JP4.1, JP5.5, JP7.SLEEVE, K1.1B, K2.2B, K3.2A, K4.2B, MOD1.GND, MOD1.RFGND, R2.2, R8.1, R19.1, R20.1, R21.1, R23.1, R25.1, R27.1, R32.1, R33.1, R35.1, R39.1, R40.2, R45.1, R48.1, R49.1, R50.1, R63.2, R64.2, TP1.TP, TP2.TP, U$1.2 (N), U$1.3 (SW), U$2.8 (VSSA(P8)), U$2.23 (VSS_1(P23)), U$2.35 (VSS_2(P35)), U$2.47 (VSS_3(P47)), U$9.9 (GND), U$9.14 (GND), U$9.20 (GND), U$9.25 (GND), U$9.30 (GND), U$9.34 (GND), U$9.39 (GND), U$10.15 (VSS), U$11.4 (GND), U$12.G, USB.1 (VSS), USB1.GND, USB1.GND@1 (GND), USB1.GND@2 (GND), USB2.GND, USB2.GND@1 (GND), USB2.GND@2 (GND)
GND@8: U$9.6 (GND)
JX: U$2.18 (PB0/ADC_IN8/TIM3_CH3), X.TP
JY: U$2.19 (PB1/ADC_IN9/TIM3_CH4), Y.TP
KC1: JP3.8, R12.1, U$2.40 (PB4/SPI1_MISO/TIM3_CH1), U$7.1 (C1)
KC2: JP3.7, R13.1, U$2.41 (PB5/WKUP6/SPI1_MOSI/TIM3_CH2), U$7.2 (C2)
KC3: JP3.6, R14.1, U$2.42 (PB6USART1_TX/I2C1_SCL), U$7.3 (C3)
KC4: JP3.5, R15.1, U$2.45 (PB8/I2C1_SCL/TIM16_CH1/CAN_RX), U$7.4 (C4)
KEYB_DM: U$2.32 (PA11/USB_DM/CAN_RX), USB.4 (DM4)
KEYB_DP: U$2.33 (PA12/USB_DP/CAN_TX), USB.5 (DP4)
KL1: LED1.A, U$2.13 (PA3/ADC_IN3/COMP2_INP/USART2_RX)
KL2: LED2.A, U$2.14 (PA4/ADC_IN4/DAC_OUT1)
KR1: JP3.4, U$2.46 (PB9/I2C1_SDA/TIM17_CH1/CAN_TX), U$7.5 (R1)
KR2: JP3.3, U$2.2 (PC13/WKUP2/RTC_TAMP1/RTC_TS/RTC_OUT), U$7.6 (R2)
KR3: JP3.2, U$2.3 (PC14/OSC32_IN), U$7.7 (R3)
KR4: JP3.1, U$2.4 (PC15/OSC32_OUT), U$7.8 (R4)
MK1: K2.1A, U$2.10 (PA0/USART4_TX/WKUP1/ADC_IN0)
MK2: K3.1B, U$2.11 (PA1/ADC_IN1/COMP1_INP/USART4_RX)
MK3: K1.1A, R16.2, U$2.12 (PA2/ADC_IN2/WKUP4USART2_TX)
unnamed: C35.2, R51.1, USB.20 (VDD5)
unnamed: C17.2, IC4.2 (SW), U$3.P$1
unnamed: JP6.3, R58.2
unnamed: IC7.6 (SCK), U$2.26 (PB13/SPI2_SCK/I2C2_SCL)
unnamed: R59.2, R62.1, T4.1 (B)
unnamed: JP6.4, R59.1
unnamed: IC1.1 (SEN), R4.2, T2.1 (S), T2.2 (S), T2.3 (S)
unnamed: USB.9 (DP2), USB2.D+
unnamed: USB.8 (DM2), USB2.D-
unnamed: USB.10 (DM1), USB1.D-
unnamed: IC1.8 (DRV), T2.4 (G)
unnamed: IC1.4 (EN), R3.2
unnamed: USB.11 (DP1), USB1.D+
unnamed: C34.2, USB.13 (VD33), USB.17 (XRSTJ), USB.18 (VBUSM), USB.19 (BUSJ), USB.21 (VD33_O), USB.26 (OVCJ)
unnamed: IC1.7 (VBAT), PTC2.P$2 (2), T2.5 (D), T2.6 (D), T2.7 (D), T2.8 (D), T3.5 (D), T3.6 (D), T3.7 (D), T3.8 (D)
unnamed: C33.2, USB.12 (VD18_O), USB.28 (VD18)
unnamed: C5.1, IC1.5 (TMR)
unnamed: C17.1, IC4.6 (VBST)
unnamed: R50.2, USB.14 (REXT)
unnamed: IC4.4 (VFB), R22.2, R23.2
unnamed: C31.2, USB.2 (XOUT), X9.P$1
unnamed: C18.2, IC5.2 (SW), U$4.P$1
unnamed: C18.1, IC5.6 (VBST)
unnamed: C37.2, USB.3 (XIN), X9.P$2
unnamed: C45.+, C46.+, R65.1, USB1.VBUS, USB2.VBUS
unnamed: IC7.2 (SO), U$2.27 (PB14/SPI2_MISO/I2C2_SDA)
unnamed: IC10.6 (1Y), R56.2
unnamed: IC10.4 (2Y), R57.2
unnamed: C43.2, R56.1, R64.1, U$12.T2
unnamed: C41.2, R57.1, R63.1, U$12.T1
unnamed: C47.-, JP7.TIP (LEFT)
unnamed: C48.-, JP7.RING (RIGHT)
unnamed: C47.+, R60.2, U$11.1 (OUT1)
unnamed: C48.+, R61.2, U$11.7 (OUT2)
unnamed: C32.+, R44.1, R45.2, U$11.3 (IN1+), U$11.5 (IN2+)
unnamed: R54.2, R60.1, U$11.2 (IN1-)
unnamed: R55.2, R61.1, U$11.6 (IN2-)
unnamed: C39.+, R54.1
unnamed: C36.+, R55.1
unnamed: C36.-, U$12.W2
unnamed: C39.-, U$12.W1
unnamed: ANT1.1, MOD1.ANT
unnamed: C38.2, R52.1, R53.1
unnamed: IC5.4 (VFB), R24.2, R25.2
unnamed: C19.2, IC6.2 (SW), U$5.P$1
unnamed: C19.1, IC6.6 (VBST)
unnamed: JP2.1, U$2.34 (PA13/SWDIO)
unnamed: IC6.4 (VFB), R26.2, R27.2
unnamed: C4.1, IC3.3 (IN), R7.2
unnamed: JP2.3, U$2.37 (PA14/USART2_TX/SWCLK)
unnamed: D2.A, R8.2, T1.4 (G)
unnamed: PTC1.P$2 (2), U$1.1
unnamed: IC10.1 (1A), R46.1, R48.2
unnamed: IC10.3 (2A), R47.1, R49.2
unnamed: C1.2, U$2.5 (PF0/OSC_IN), X1.P$1
unnamed: U$2.30 (PA9/USART1_TX/TIM1_CH2), X5.TP
unnamed: IC7.5 (SI), U$2.28 (PB15/WKUP7/RTC_REFIN/SPI2_MOSI)
unnamed: IC7.1 (!CS), R9.2, U$2.29 (PA8/TIM1_CH1)
unnamed: U$2.31 (PA10/USART1_RX/TIM1_CH3), X6.TP
unnamed: U$2.15 (PA5/ADC_IN5/DAC_OUT2/SPI1_SCK), X2.TP
unnamed: R2.1, U$2.44 (BOOT0(P44))
unnamed: LED1.K (C), R19.2
unnamed: LED2.K (C), R20.2
unnamed: LED4.A, U$10.10 (PA4)
unnamed: LED3.A, U$10.9 (PA3)
unnamed: JP2.2, R1.1, U$2.7 (NRST(P7))
unnamed: R30.2, U$10.17 (PA9)
unnamed: R31.2, U$10.18 (PA10)
unnamed: R28.2, U$10.13 (PA7)
unnamed: R29.2, U$10.12 (PA6)
unnamed: U$2.16 (PA6/ADC_IN6/SPI1_MISO/TIM3_CH1), X3.TP
unnamed: U$2.17 (PA7/ADC_IN7/SPI1_MOSI/TIM3_CH2), X4.TP
unnamed: U$2.38 (PA15/USART2_RX), X7.TP
unnamed: U$2.39 (PB3/SPI1_SCK/TIM2_CH2), X8.TP
unnamed: JP5.1, U$10.19 (PA13/SWDIO)
unnamed: JP5.3, U$10.20 (PA14/SWCLK)
unnamed: JP5.2, R41.1, U$10.4 (!RST)
unnamed: JP1.1, PTC2.P$1 (1)
unnamed: K4.1A, R42.1, U$10.3 (PF1/OSCO)
unnamed: C2.2, U$2.6 (PF1/OSC_OUT), X1.P$2
unnamed: IC8.3 (VBAT), U$6.POS
unnamed: R21.2, U$6.N (M)
unnamed: LED3.K (C), R32.2
unnamed: LED4.K (C), R33.2
unnamed: K3.2B, R18.2
unnamed: IC8.2 (OSO), Q1.4 (2)
unnamed: IC8.1 (OSI), Q1.1
unnamed: K2.2A, R17.2
unnamed: JP6.5, TFT1.3 (SCK)
unnamed: T4.3 (C), TFT1.11 (LEDK1), TFT1.12 (LEDK2), TFT1.13 (LEDK3), TFT1.14 (LEDK4)
unnamed: IC1.3 (STAT), R5.1
unnamed: C30.2, MOD1.3V3, R36.2
unnamed: IC9.3 (NEIN+), R34.1, R35.2
unnamed: C3.1, IC2.3 (IN), R6.1
unnamed: R40.1, U$10.1 (BOOT0)
unnamed: D1.C, D3.A, PTC1.P$1 (1), T1.5 (D), T1.6 (D), T1.7 (D), T1.8 (D), T3.4 (G)
unnamed: R58.1, TFT1.10 (LEDA)
unnamed: JP6.2, R62.2, TFT1.9 (VDD)
unnamed: JP6.1, T4.2 (E), TFT1.1 (GND1), TFT1.8 (GND2)
unnamed: JP6.6, TFT1.6 (SDA)
unnamed: JP6.7, TFT1.5 (CS)
unnamed: JP6.8, TFT1.4 (D/C)
unnamed: JP6.9, TFT1.2 (RST)
PWM0: R47.2, U$9.12 (GPIO18)
PWM1: R46.2, U$9.33 (GPIO13)
RPG1: R28.1, U$9.35 (GPIO19)
RPG2: R29.1, U$9.37 (GPIO26)
RPRX: R30.1, U$9.10 (RXD0/GPIO15)
RPTX: R31.1, U$9.8 (TXD0/GPIO14)
RST: JP4.9, U$9.22 (GEN/6GPIO25)
R_SCL: IC8.6 (SCL), R10.1, U$9.5 (GPIO3/SCL1)
R_SDA: IC8.5 (SDA), R11.1, U$9.3 (GPIO2/SDA1)
SCK: JP4.5, R37.1
SCK_R: R37.2, U$9.23 (GPIO11/SCLK)
SDA: JP4.6, U$9.19 (GPIO10/MOSI)
V25A: C42.2, IC10.5 (VDD), IC11.2 (OUT)
V50A: C40.2, C44.+, IC11.3 (IN), R44.2, R53.2, U$11.8 (VDD)
VCC: C6.1, C8.1, C9.1, C10.1, IC3.2 (OUT), IC7.8 (VDD), JP2.4, R1.2, R9.1, R12.2, R13.2, R14.2, R15.2, R16.1, R17.1, R18.1, U$2.1 (VBATT(P1)), U$2.9 (VDDA(P9)), U$2.24 (VDD_1(P24)), U$2.36 (VDDIO2(P36)), U$2.48 (VDD_2(P48)), VDD.TP
VDD: C23.1, IC8.8 (VDD), JP4.2, R10.2, R11.2, U$9.1 (3V3)
WL_D+: MOD1.D+, USB.7 (DP3)
WL_D-: MOD1.D-, USB.6 (DM3)

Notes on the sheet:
POWER SUPPLY
USB USER IO
RPI ZERO
POWER MONITOR
WIFI
LCD
USB HUB
AUDIO
raspberry pi zero portable computer
project A
jaromir.sukuba@gmail.com
RTC
22k/470p/DNP/10k(pot) alternatively

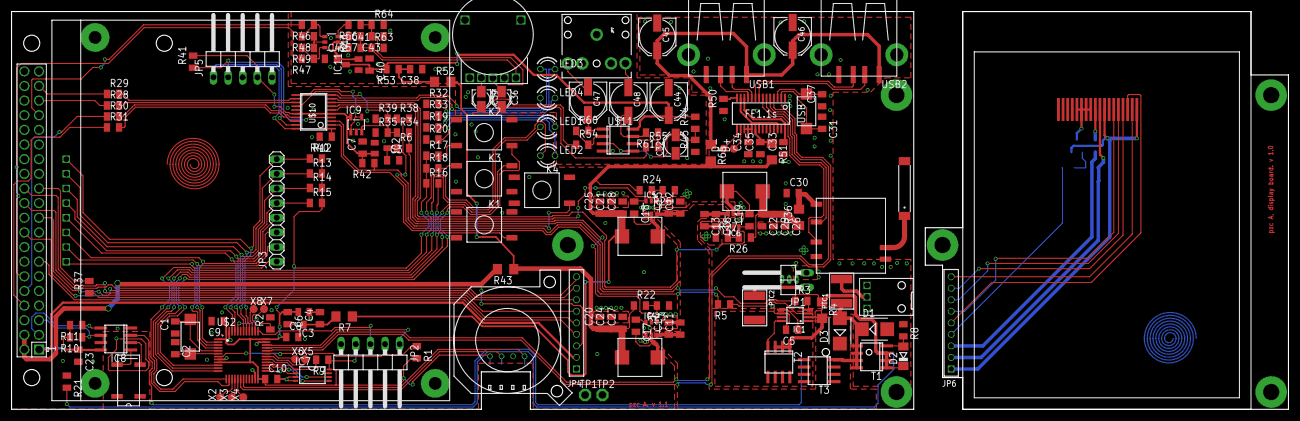
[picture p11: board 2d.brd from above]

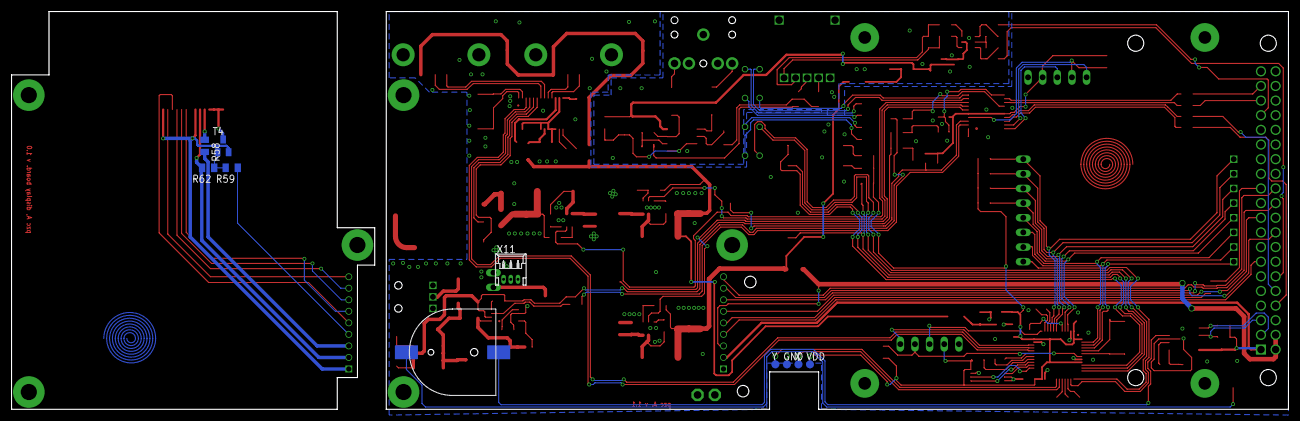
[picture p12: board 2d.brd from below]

Board: 2 copper layers, 221.5 x 69.0 mm, 185 parts (10 on the bottom side), 157 nets.

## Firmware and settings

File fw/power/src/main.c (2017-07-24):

#include "stm32l0xx.h"

#include <stdio.h>
#include <string.h>
#include <stdlib.h>

uint8_t tmp,btn_cnt,state,state_change;

void dly_ms (void);
void dly_nms (uint16_t num);

#define	LED_G_MASK	0x08
#define	LED_O_MASK	0x10

#define	OUT_5VM_MASK	0x01
#define	OUT_5VU_MASK	0x02
#define	OUT_3V_MASK	0x04

#define	OUT_5VM_ON	GPIOA->BSRR = GPIOA->BSRR | (OUT_5VM_MASK<<0)
#define	OUT_5VM_OFF	GPIOA->BSRR = GPIOA->BSRR | (OUT_5VM_MASK<<16)
#define	OUT_5VU_ON	GPIOA->BSRR = GPIOA->BSRR | (OUT_5VU_MASK<<0)
#define	OUT_5VU_OFF	GPIOA->BSRR = GPIOA->BSRR | (OUT_5VU_MASK<<16)
#define	OUT_3V_ON	GPIOA->BSRR = GPIOA->BSRR | (OUT_3V_MASK<<0)
#define	OUT_3V_OFF	GPIOA->BSRR = GPIOA->BSRR | (OUT_3V_MASK<<16)

#define	LED_G_ON	GPIOA->BSRR = GPIOA->BSRR | (LED_G_MASK<<0)
#define	LED_G_OFF	GPIOA->BSRR = GPIOA->BSRR | (LED_G_MASK<<16)
#define	LED_O_ON	GPIOA->BSRR = GPIOA->BSRR | (LED_O_MASK<<0)
#define	LED_O_OFF	GPIOA->BSRR = GPIOA->BSRR | (LED_O_MASK<<16)

#define	BTN_STATE	(!(GPIOC->IDR&0x8000))

#define	CHG_STATE	(!(GPIOC->IDR&0x4000))


void power_on (void);
void power_off (void);
void adc_init (void);
void adc_uninit (void);
uint16_t adc_get (uint8_t channel);
uint16_t get_volt_in (void);
uint16_t get_volt_batt (void);
void usart_init (void);
void usart_uninit (void);
void usart_send_byte(uint8_t data);
void usart_send_str (uint8_t * data);

void EXTI15_4_IRQHandler(void)
    {
//	LED_O_ON;
	EXTI->PR = EXTI->PR | (1<<15);
    }


uint8_t main_state,btn_cnt,volt_bat_cnt;
uint16_t volt_bat,volt_in;

volatile uint8_t rx_msg[50],rx_msg_ptr,rx_flag;
uint8_t tx_msg[50];


#define	MAIN_STATE_SHUTDOWN	1
#define	MAIN_STATE_RUN		2
#define	MAIN_STATE_RUN_ENTRY	3
#define	MAIN_STATE_RUN_ENTRY2	4
#define MAIN_STATE_SHDN_ENTRY	5

#define	ADC_BATT		5
#define	ADC_IN			7
#define	ADC_VREF		3300
#define	ADC_BATT_R1		100
#define	ADC_BATT_R2		27
#define	ADC_IN_R1		560
#define	ADC_IN_R2		100

uint16_t ledg_cnt, ledg_state;


int main (void)
    {
    RCC->IOPENR = RCC_IOPENR_GPIOAEN | RCC_IOPENR_GPIOBEN | RCC_IOPENR_GPIOCEN;
    RCC->APB2ENR = RCC->APB2ENR | RCC_APB2ENR_SYSCFGEN;
    RCC->APB1ENR = RCC->APB1ENR | RCC_APB1ENR_PWREN;
//    RCC->CFGR = RCC->CFGR | (0x09<<4);
    RCC->CR = RCC->CR & ~(RCC_CR_HSEON);
    GPIOA->MODER = GPIOA->MODER & 0xFFFF0000;
    GPIOA->MODER = GPIOA->MODER | (0b01<<(2*0)) | (0b01<<(2*1)) | (0b01<<(2*2)) | (0b01<<(2*3)) | (0b01<<(2*4));
    GPIOA->MODER = GPIOA->MODER | (0b11<<(2*5));
    GPIOA->MODER = GPIOA->MODER | (0b11<<(2*7));
    GPIOC->PUPDR = GPIOC->PUPDR | (0b01<<(2*15)) | (0b01<<(2*14));
    GPIOC->MODER = GPIOC->MODER & (0x3FFFFFFF);
    GPIOC->MODER = GPIOC->MODER & (0xCFFFFFFF);

    SYSCFG->EXTICR[3] = (0b0010<<12);
    EXTI->FTSR = (1<<15);
    EXTI->IMR = (1<<15);
    NVIC_SetPriority(EXTI4_15_IRQn,1);
    NVIC_EnableIRQ(EXTI4_15_IRQn);
    main_state=MAIN_STATE_RUN_ENTRY2;
    while (1)
	{
	dly_nms(10);
	if (rx_flag)
	    {
	    rx_flag = 0;
	    if (strncmp(rx_msg,"gtv",3)==0)
		{
		usart_send_str("gtv: ");
		usart_send_str("pz_c ver 0.9");
		}
	    if (strncmp(rx_msg,"gvb",3)==0)
		{
		usart_send_str("gvb: ");
		itoa(volt_bat,tx_msg,10);
		usart_send_str(tx_msg);
		}
	    if (strncmp(rx_msg,"gve",3)==0)
		{
		usart_send_str("gve: ");
		itoa(volt_in,tx_msg,10);
		usart_send_str(tx_msg);
		}
	    if (strncmp(rx_msg,"gcs",3)==0)
		{
		usart_send_str("gcs: ");
		if (CHG_STATE)
		    usart_send_str("1");
		else
		    usart_send_str("0");
		}
	    usart_send_str("\r\n");
	    }
	if (main_state==MAIN_STATE_SHUTDOWN)
	    {
	    power_off();
	    main_state=MAIN_STATE_RUN_ENTRY;
	    btn_cnt = 0;
	    }
	if (main_state==MAIN_STATE_RUN_ENTRY)
	    {
		LED_G_ON;
	    if (BTN_STATE)
			{
			btn_cnt++;
			if (btn_cnt>50)
				{
				main_state=MAIN_STATE_RUN_ENTRY2;
				}
			}
	    else
			{
	    	btn_cnt=0;
	    	main_state = MAIN_STATE_SHUTDOWN;
			}
	    }
	 if (main_state==MAIN_STATE_RUN_ENTRY2)
	    {
		LED_O_ON;
	    if (!(BTN_STATE))
		{
	    LED_O_OFF;
		power_on();
		main_state=MAIN_STATE_RUN;
		}
	    }
	if (main_state==MAIN_STATE_SHDN_ENTRY)
	    {
	    LED_G_OFF;
	    if (!(BTN_STATE))
		{
		dly_nms(250);
		main_state = MAIN_STATE_SHUTDOWN;
		}
	    }
	if (main_state==MAIN_STATE_RUN)
	    {
	    volt_bat = get_volt_batt();
	    dly_nms(1);
	    volt_in = get_volt_in();
	    dly_nms(1);
	    if (CHG_STATE)
		LED_O_ON;
	    else
		LED_O_OFF;
	    if (BTN_STATE)
			{
			btn_cnt++;
			if (btn_cnt>100)
				{
				main_state=MAIN_STATE_SHDN_ENTRY;
				}
			}
	    else
			{
	    	btn_cnt=0;
			}
	    if (volt_bat<6500)
	    	{
	    	volt_bat_cnt++;
	    	if (volt_bat_cnt>40)
	    		main_state=MAIN_STATE_SHDN_ENTRY;
	    	}
	    else
	    	volt_bat_cnt = 0;
	    if (volt_bat < 7000)
	    	{
	    	if (ledg_state==0) ledg_state = 1;
	    	}
	    else
	    	{
	    	if (ledg_state>0) ledg_state = 0;
	    	}
		ledg_cnt++;
		if (ledg_state==1)
			{
			if (ledg_cnt>10)
				{
				LED_G_ON;
				ledg_cnt=0;
				ledg_state = 2;
				}
			}
		if (ledg_state==2)
			{
			if (ledg_cnt>190)
				{
				LED_G_OFF;
				ledg_cnt=0;
				ledg_state = 1;
				}
			}
		if (ledg_state==0) LED_G_ON;


	    }
	}
    }

void USART2_IRQHandler(void)
{
uint8_t b;
b = USART2->RDR;
if (b>=' ')
    {
    rx_msg[rx_msg_ptr++] = b;
    if (rx_msg_ptr>50) rx_msg_ptr = 0;
    }
else
    {
    if (rx_msg_ptr>2)
	{
	rx_msg[rx_msg_ptr++] = 0;
	rx_msg_ptr = 0;
	rx_flag = 1;
	}
    else
	rx_msg_ptr = 0;
    }
}


void usart_init (void)
    {
    RCC->APB1ENR = RCC->APB1ENR | RCC_APB1ENR_USART2EN;
    GPIOA->MODER = GPIOA->MODER & ~((0b11<<(2*9)) | (0b11<<(2*10)));
    GPIOA->MODER = GPIOA->MODER | (0b10<<(2*9)) | (0b10<<(2*10));
    USART2->BRR = 2100000 / 9600;
    USART2->CR1 = USART_CR1_UE | USART_CR1_RE | USART_CR1_TE;
    GPIOA->AFR[1] = GPIOA->AFR[1] | (0b0100<<(4*1)) | (0b0100<<(4*2));
    USART2->CR1 = USART2->CR1 | USART_CR1_RXNEIE ;
    NVIC_EnableIRQ(USART2_IRQn);
    }

void usart_uninit (void)
    {

    USART2->CR1 = 0;

    }

void usart_send_byte(uint8_t data)
    {

    while (((USART2->ISR)&USART_ISR_TXE)==0);
    USART2->TDR = data;

    }


void usart_send_str (uint8_t * data)
    {
    while (*data) usart_send_byte(*data++);
    }


uint16_t get_volt_in (void)
    {
    uint32_t tmp;
    tmp = adc_get(ADC_IN);

    tmp = tmp * ADC_VREF;
    tmp = tmp * (ADC_IN_R1+ADC_IN_R2);
    tmp = tmp / ADC_IN_R2;
    tmp = tmp / 4096;
    return tmp;
    }

uint16_t get_volt_batt (void)
    {
    uint32_t tmp;
    tmp = adc_get(ADC_BATT);
    tmp = tmp * ADC_VREF;
    tmp = tmp * (ADC_BATT_R1+ADC_BATT_R2);
    tmp = tmp / ADC_BATT_R2;
    tmp = tmp / 4096;
    return tmp;
    }


void adc_init (void)
{
RCC->APB2ENR = RCC->APB2ENR | RCC_APB2ENR_ADC1EN;
ADC1->CFGR1 = 0x00;
ADC1->CFGR2 = 0x40000000;
ADC1->SMPR = 0x07;
ADC1->CR = ADC_CR_ADCAL;
while (ADC1->CR & ADC_CR_ADCAL);
ADC1->CR = 0x01;
}

void adc_uninit (void)
    {
    ADC1->CR = ADC_CR_ADDIS;
    while (ADC1->CR&ADC_CR_ADDIS);
    RCC->APB2ENR = RCC->APB2ENR & (~RCC_APB2ENR_ADC1EN);
    }

uint16_t adc_get (uint8_t channel)
{
ADC1->CHSELR = (1<<channel);
ADC1->CR = ADC1->CR | 0x04;
while (ADC1->CR & 0x04);
return ADC1->DR;
}

void power_on (void)
    {
	LED_G_ON;
	OUT_5VM_ON;
	OUT_5VU_ON;
	OUT_3V_ON;
	adc_init();
	usart_init();
    }



void power_off (void)
    {
    adc_uninit();
    usart_uninit();
    LED_G_OFF;
    LED_O_OFF;
    OUT_5VM_OFF;
    OUT_5VU_OFF;
    OUT_3V_OFF;
//    PWR->CR = PWR->CR | PWR_CR_LPSDSR | PWR_CR_PDDS;

   PWR->CR = PWR->CR | PWR_CR_LPSDSR;
    SCB->SCR |= SCB_SCR_SLEEPDEEP_Msk;
    __WFI();
    }


void dly_ms (void)
    {
    volatile uint32_t cnt;
    for (cnt=0;cnt<190;cnt++);
    }


void dly_nms (uint16_t num)
    {
    uint16_t i;
    for (i=0;i<num;i++) dly_ms();

    }

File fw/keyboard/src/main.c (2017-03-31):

/*
 *
 *
 *
 */



#include "main.h"  

USBD_HandleTypeDef USBD_Device;

static void SystemClock_Config(void);
int main(void)
{
  HAL_Init();
  
  SystemClock_Config();
  adc_init();
  keyb_init();
  mouse_button_Init();
  
//  BSP_PB_Init(BUTTON_USER, BUTTON_MODE_EXTI);
  USBD_Init(&USBD_Device, &HID_Desc, 0);
  USBD_RegisterClass(&USBD_Device, &USBD_HID);
  USBD_Start(&USBD_Device);
  
  while (1)
  {
  }
}


static void SystemClock_Config(void)
{
  RCC_ClkInitTypeDef RCC_ClkInitStruct;
  RCC_OscInitTypeDef RCC_OscInitStruct;
  RCC_PeriphCLKInitTypeDef  PeriphClkInitStruct;
  
#if defined (USE_USB_CLKSOURCE_CRSHSI48)
  static RCC_CRSInitTypeDef RCC_CRSInitStruct;
#endif
  
#if defined (USE_USB_CLKSOURCE_CRSHSI48)
  
  /* Enable HSI48 Oscillator to be used as system clock source */
  RCC_OscInitStruct.OscillatorType = RCC_OSCILLATORTYPE_HSI48;
  HAL_RCC_OscConfig(&RCC_OscInitStruct); 
  
  /* Select HSI48 as USB clock source */
  PeriphClkInitStruct.PeriphClockSelection = RCC_PERIPHCLK_USB;
  PeriphClkInitStruct.UsbClockSelection = RCC_USBCLKSOURCE_HSI48;
  HAL_RCCEx_PeriphCLKConfig(&PeriphClkInitStruct);
  
  /* Select HSI48 as system clock source and configure the HCLK and PCLK1 
  clock dividers */
  RCC_ClkInitStruct.ClockType = (RCC_CLOCKTYPE_SYSCLK | RCC_CLOCKTYPE_HCLK | RCC_CLOCKTYPE_PCLK1);
  RCC_ClkInitStruct.SYSCLKSource = RCC_SYSCLKSOURCE_HSI48;
  RCC_ClkInitStruct.AHBCLKDivider = RCC_SYSCLK_DIV1;
  RCC_ClkInitStruct.APB1CLKDivider = RCC_HCLK_DIV1;  
  HAL_RCC_ClockConfig(&RCC_ClkInitStruct, FLASH_LATENCY_1);
  
  /*Configure the clock recovery system (CRS)**********************************/
  
  /*Enable CRS Clock*/
  __HAL_RCC_CRS_CLK_ENABLE(); 
  
  /* Default Synchro Signal division factor (not divided) */
  RCC_CRSInitStruct.Prescaler = RCC_CRS_SYNC_DIV1;
  
  /* Set the SYNCSRC[1:0] bits according to CRS_Source value */
  RCC_CRSInitStruct.Source = RCC_CRS_SYNC_SOURCE_USB;
  
  /* HSI48 is synchronized with USB SOF at 1KHz rate */
  RCC_CRSInitStruct.ReloadValue =  __HAL_RCC_CRS_RELOADVALUE_CALCULATE(48000000, 1000);
  RCC_CRSInitStruct.ErrorLimitValue = RCC_CRS_ERRORLIMIT_DEFAULT;
  
  /* Set the TRIM[5:0] to the default value*/
  RCC_CRSInitStruct.HSI48CalibrationValue = 0x20; 
  
  /* Start automatic synchronization */ 
  HAL_RCCEx_CRSConfig (&RCC_CRSInitStruct);
  
#elif defined (USE_USB_CLKSOURCE_PLL)
  
  /* Enable HSE Oscillator and activate PLL with HSE as source
  PLLCLK = (8 * 6) / 1) = 48 MHz */
  RCC_OscInitStruct.OscillatorType = RCC_OSCILLATORTYPE_HSE;
  RCC_OscInitStruct.HSEState = RCC_HSE_ON;
  RCC_OscInitStruct.PLL.PLLState = RCC_PLL_ON;
  RCC_OscInitStruct.PLL.PLLSource = RCC_PLLSOURCE_HSE;
  RCC_OscInitStruct.PLL.PLLMUL = RCC_PLL_MUL6;
  RCC_OscInitStruct.PLL.PREDIV = RCC_PREDIV_DIV1;
  HAL_RCC_OscConfig(&RCC_OscInitStruct); 
  
  /*Select PLL 48 MHz output as USB clock source */
  PeriphClkInitStruct.PeriphClockSelection = RCC_PERIPHCLK_USB;
  PeriphClkInitStruct.UsbClockSelection = RCC_USBCLKSOURCE_PLL;
  HAL_RCCEx_PeriphCLKConfig(&PeriphClkInitStruct);
  
  /* Select PLL as system clock source and configure the HCLK and PCLK1 
  clock dividers */
  RCC_ClkInitStruct.ClockType = (RCC_CLOCKTYPE_SYSCLK | RCC_CLOCKTYPE_HCLK | RCC_CLOCKTYPE_PCLK1);
  RCC_ClkInitStruct.SYSCLKSource = RCC_SYSCLKSOURCE_PLLCLK;
  RCC_ClkInitStruct.AHBCLKDivider = RCC_SYSCLK_DIV1;
  RCC_ClkInitStruct.APB1CLKDivider = RCC_HCLK_DIV1;  
  HAL_RCC_ClockConfig(&RCC_ClkInitStruct, FLASH_LATENCY_1);
  
#endif /*USE_USB_CLKSOURCE_CRSHSI48*/
  
  /* Enable Power Controller clock */
  __HAL_RCC_PWR_CLK_ENABLE();
}



#ifdef  USE_FULL_ASSERT

/**
  * @brief  Reports the name of the source file and the source line number
  *         where the assert_param error has occurred.
  * @param  file: pointer to the source file name
  * @param  line: assert_param error line source number
  * @retval None
  */
void assert_failed(uint8_t* file, uint32_t line)
{ 
  /* User can add his own implementation to report the file name and line number,
     ex: printf("Wrong parameters value: file %s on line %d\r\n", file, line) */

  /* Infinite loop */
  while (1)
  {
  }
}
#endif

/************************ (C) COPYRIGHT STMicroelectronics *****END OF FILE****/

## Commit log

2017-01-14 first hw
    [rpzc_1.brd, rpzc_1.sch]
2017-03-31 new version, a bit messy
    [2d.brd, 2d.sch, f072_g.cfg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]
2017-07-24 rev 2
    [2i.brd, 2i.sch, custom_l11.cfg]
2017-07-25 rev 3
    added mechanical files, BOM
    [1c_btm.stl, 1c_btn.stl, 1c_main.stl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]

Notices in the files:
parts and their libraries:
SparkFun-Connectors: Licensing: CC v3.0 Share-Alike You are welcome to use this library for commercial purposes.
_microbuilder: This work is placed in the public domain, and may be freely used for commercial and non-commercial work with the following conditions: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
